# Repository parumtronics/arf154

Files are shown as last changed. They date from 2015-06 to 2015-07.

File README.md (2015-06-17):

# arf154 

Arf154 is an arduino compatible wireless network ready board.

The board core is the atsamr21g1x SoC. The device integrates a Cortex-M0 and a
IEEE 802.15.4 transceiver.

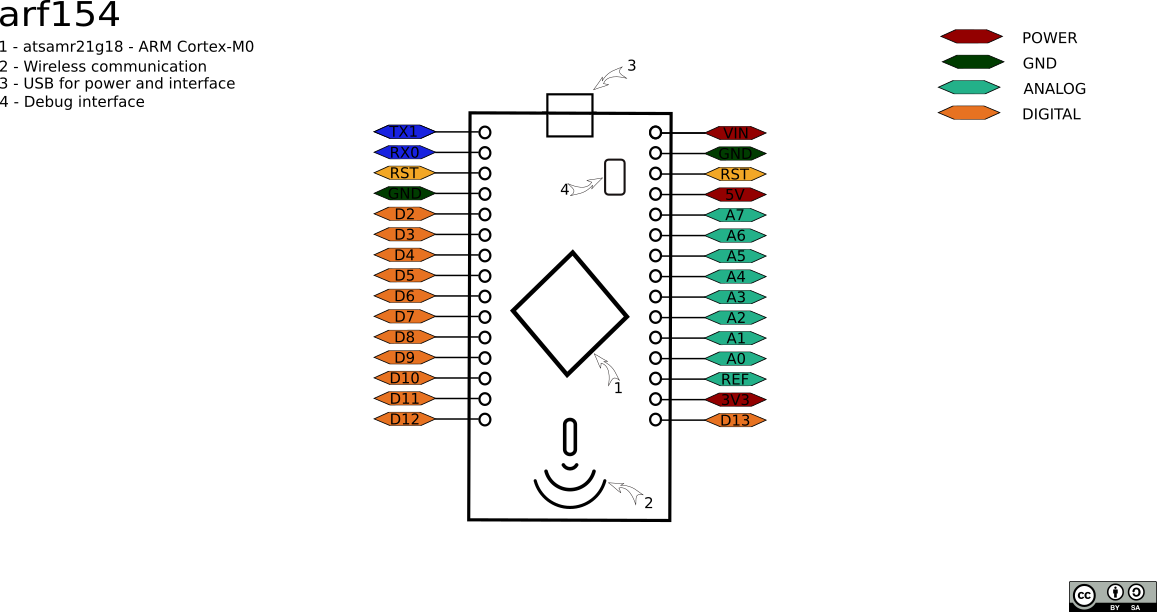
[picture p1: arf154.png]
Diagram


## Footprint

The design is targeting to be as compatible as possible with Arduino nano.

## How to program

The board can be programmed using the USB connector or trough the EMDBG using 
any Atmel software tools.

## Libraries

At this moment, there's no library but basic wireless communication libraries 
will be added in near future. Support for advanced features, as mesh network,
will be added later.

The board also is compatible with zigbee, 6lowpan and other network standart.

## Status

At this moment the schematics are almost done.

LICENSE: All work is released under the MIT license.

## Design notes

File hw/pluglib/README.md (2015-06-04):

# Pluglib

Kicad libraries for components used in the plugfects projects.

Parts are divided in the following categories

* Processing
* Analog
* Sensor

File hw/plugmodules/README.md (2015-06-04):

# plugmodules
Modular circuits library for kicad

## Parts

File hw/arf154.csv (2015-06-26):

Id | Designator | Package | Quantity | Designation | Supplier and ref
1 | C1 | C_0603_HandSoldering | 1 | 10uF
2 | C2,C3,C4,C5,C6,C7,C8,C10 | C_0603_HandSoldering | 8 | 100n
3 | C9,C11 | C_0603_HandSoldering | 2 | 10u
4 | P1,P2 | Pin_Header_Straight_1x15 | 2 | CONN_01X15
5 | P3 | Pin_Header_Straight_2x05 | 1 | CONN_02X05
6 | R1,R2 | R_0603_HandSoldering | 2 | 100K
7 | R3 | R_0603_HandSoldering | 1 | 10K
8 | U2 | SOT-223 | 1 | LD1117S33TR

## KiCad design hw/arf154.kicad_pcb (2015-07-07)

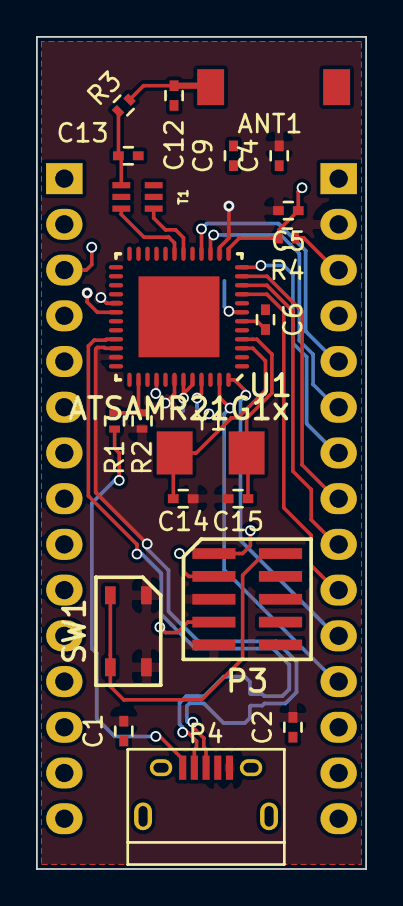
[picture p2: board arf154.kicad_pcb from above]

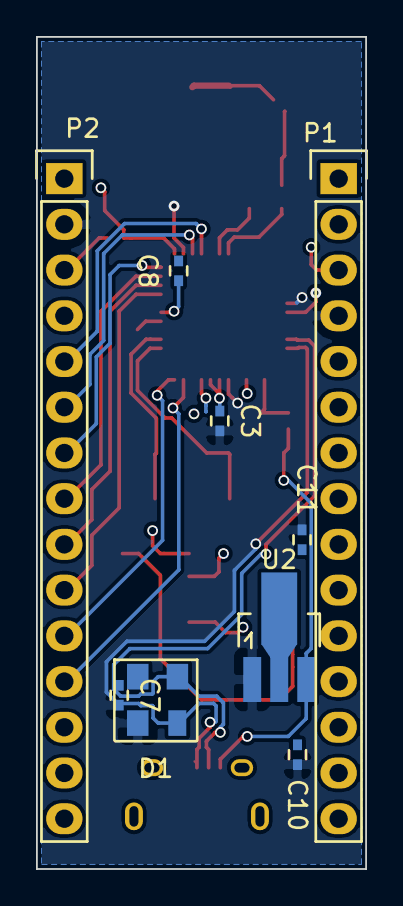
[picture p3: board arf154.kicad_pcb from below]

Board: 4 copper layers, 18.3 x 46.2 mm, 30 parts (9 on the bottom side), 26 nets.

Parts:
ANT1: antenna; CHIPANTENNA2dBi
C1: 10uF; C_0402
C2, C3, C4, C5, C6, C7, C8, C10: 100n; C_0402
C9, C11: 10u; C_0402
C12, C13: xF; C_0402
C14, C15: 18pF; C_0402
D1: PRTR5V0U2X; SOT143B
P1: Cn1; Pin_Header_Straight_1x15
P2: Cn2; Pin_Header_Straight_1x15
P3: CONN_02X05; CMxDBG
P4: USB_B; USB_Micro-B
R1, R2: 100K; R_0402
R3: xR; R_0402
R4: 10K; R_0402
SW1: SW_PUSH; tactileswitch
T1: 2450BM15A0015; JBALUN
U1: ATSAMR21G1x; QFN48EP
U2: AZ1117C; SOT89-3_Housing_Handsoldering
Y1: 16MHz; 2SMD

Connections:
/MainProcessor/BD+: T1.4, U1.18
/MainProcessor/BD-: T1.3, U1.19
/MainProcessor/PA4: P2.10, U1.9
/MainProcessor/PA5: P2.9, U1.10
/MainProcessor/PA6: P2.8, U1.11
/MainProcessor/PA7: P2.7, U1.12
/MainProcessor/PA8: P2.6, U1.15
/MainProcessor/PA9: P2.5, U1.16
/MainProcessor/PA23: R1.2, R2.1, U1.32
/MainProcessor/PB2: P2.12, U1.47
/MainProcessor/PB3: P2.11, U1.48
/MainProcessor/RST: C7.1, P1.3, P2.3, P3.10, R4.1, SW1.2, U1.40
/MainProcessor/SWCLK: P3.4, U1.45
/MainProcessor/SWDIO: P3.2, U1.46
/Sheet557215E3/D+: D1.3, P4.2, U1.33
/Sheet557215E3/D-: D1.2, P4.3, U1.34
GND: C1.2, C2.2, C3.2, C4.2, C5.2, C7.2, C10.2, C11.2, C14.2, C15.2, D1.1, P1.4, P2.2, P3.3, P3.5, P3.9, P4.4, P4.5, R2.2, SW1.1, U1.14, U1.29, U1.35, U1.42, U2.1
GNDA: C6.2, C8.2, C9.2, U1.5, U1.8, U1.17, U1.20
GNDREF: C12.2, C13.2, T1.2, T1.5, T1.6
unnamed: ANT1.1, C12.1, R3.2
unnamed: C13.1, R3.1, T1.1
unnamed: C14.1, U1.3, Y1.1
unnamed: C15.1, U1.4, Y1.2
VAA: C6.1, C8.1, C9.1, U1.6, U1.7
VCC: C10.1, D1.4, P4.1, R1.1, U2.3
VDD: C1.1, C2.1, C3.1, C4.1, C5.1, C11.1, P2.14, P3.1, R4.2, U1.13, U1.30, U1.36, U1.43, U1.44, U2.2

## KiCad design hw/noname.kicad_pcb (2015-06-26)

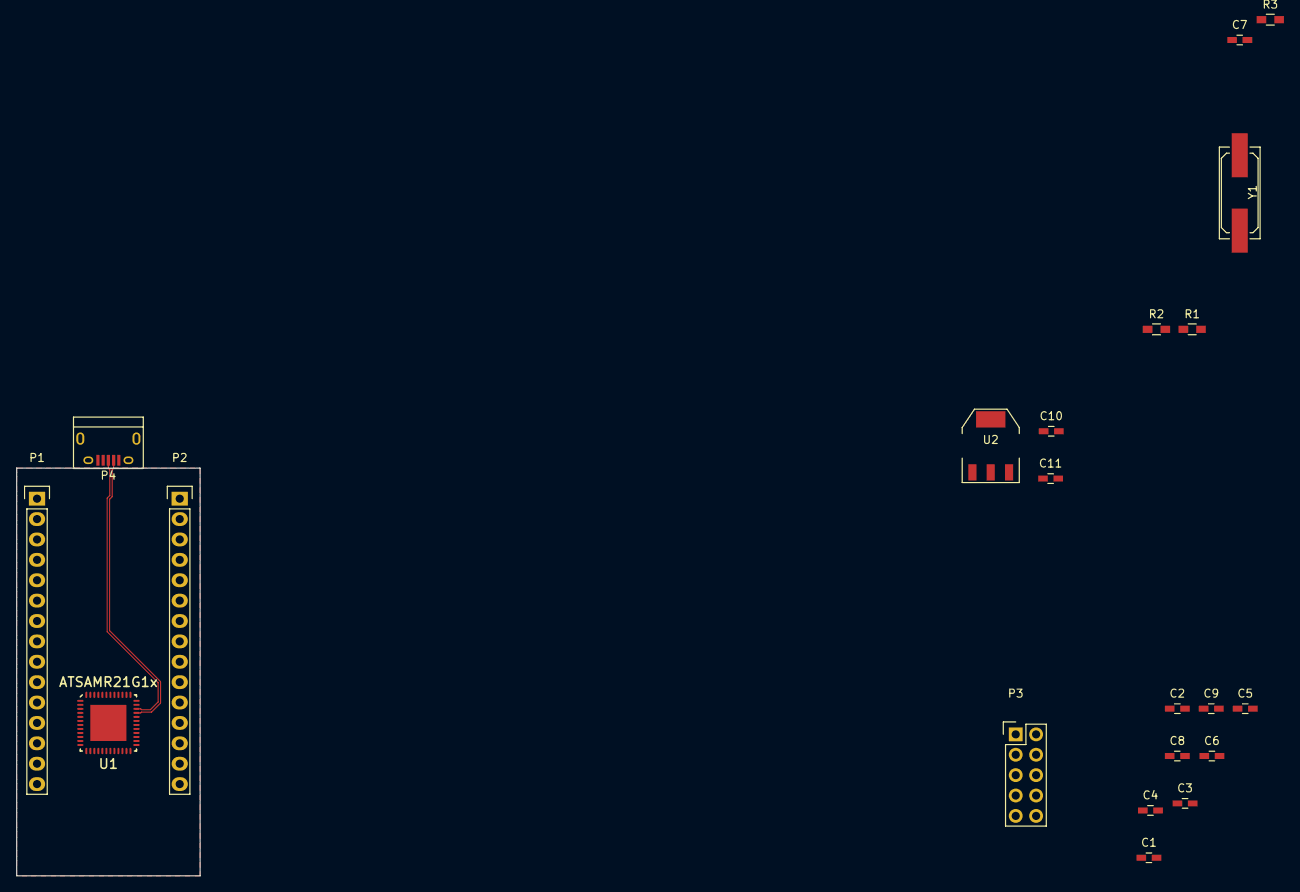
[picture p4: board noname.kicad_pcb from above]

Board: 4 copper layers, 22.9 x 50.8 mm, 21 parts (0 on the bottom side), 14 nets.

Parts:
C1: 10uF; C_0603_HandSoldering
C2, C3, C4, C5, C6, C7, C8, C10: 100n; C_0603_HandSoldering
C9, C11: 10u; C_0603_HandSoldering
P1, P2: CONN_01X15; Pin_Header_Straight_1x15
P3: CONN_02X05; Pin_Header_Straight_2x05
P4: USB_B; USB_Micro-B
R1, R2: 100K; R_0603_HandSoldering
R3: 10K; R_0603_HandSoldering
U1: ATSAMR21G1x; QFN48EP
U2: LD1117S33TR; SOT-223
Y1: 16MHz; Q_49U3HMS

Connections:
/MainProcessor/PA22: U1.31, U1.37
/MainProcessor/PA23: R1.2, R2.1, U1.32, U1.38
/MainProcessor/RST: C7.1, P3.10, R3.2, U1.40
/MainProcessor/SWCLK: P3.4, U1.45
/MainProcessor/SWDIO: P3.2, U1.46
/Sheet557215E3/D+: P4.2, U1.33
/Sheet557215E3/D-: P4.3, U1.34
GND: C1.2, C2.2, C3.2, C4.2, C5.2, C7.2, C10.2, C11.2, P3.3, P3.5, P3.9, P4.4, P4.5, R2.2, U1.14, U1.29, U1.35, U1.42, U2.1
GNDA: C6.2, C8.2, C9.2, U1.5, U1.8, U1.17, U1.20
unnamed: U1.3, Y1.1
unnamed: U1.4, Y1.2
VAA: C6.1, C8.1, C9.1, U1.6, U1.7
VCC: C10.1, P4.1, R1.1, U2.3
VDD: C1.1, C2.1, C3.1, C4.1, C5.1, C11.1, P3.1, R3.1, U1.13, U1.30, U1.36, U1.43, U1.44, U2.2

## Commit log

2015-06-04 Adding atsamr21q1x
    [atsamr21q1x.sch]
2015-06-04 Fix directory structure
    [atsamr21q1x.sch]
2015-06-04 Minor fix in MainProcessor circuit
    [atsamr21q1x.sch]
2015-06-04 Adding top design and .gitignore
    [arf154.sch]
2015-06-05 Added Balun and edbg connector
    [arf154.sch, atsamr21q1x.sch]
2015-06-05 Schematics for main processor done
    [arf154.sch, atsamr21q1x.sch]
2015-06-05 Added linear voltage regulator 3V3
    [arf154.sch, atsamr21q1x.sch, linear3v3.sch]
2015-06-05 Fix naming of atsamr21G SOC
    [arf154.sch, atsamr21q1x.sch, linear3v3.sch]
2015-06-06 Added USB circuit
    [arf154.sch, atsamr21q1x.sch, linear3v3.sch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]
2015-06-14 USB connections made, need to add protection in VBUS power flag connection to avoid problems when not powered from USB
    [arf154.sch]
2015-06-16 First schematics done. Need to finish connections and add power separation of VBUS-VCC
    [arf154.sch]
2015-06-16 Adding the cmp file with assigned parts footprint
2015-06-17 README update, Schematics almost done(need to finish power section)
    [arf154.sch, atsamr21q1x.sch, linear3v3.sch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]
2015-06-26 Started layout, minor gitignore modification
    [arf154.csv, arf154.kicad_pcb, arf154.sch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]
2015-06-28 Schematics change for a smaller regulator, added a new sch module, layout update
    [arf154.kicad_pcb, arf154.sch, atsamr21q1x.sch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]
2015-06-28 Modified power regulator
    [arf154.kicad_pcb, arf154.sch, atsamr21q1x.sch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]
2015-06-28 Layout update, footprint changed to 0402, atsam component fix
    [arf154.kicad_pcb, arf154.sch, atsamr21q1x.sch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]
2015-07-02 Layout for the analog pads and DRC fix on the USB signals
    [arf154.kicad_pcb, arf154.sch]
2015-07-04 Layout updated, need improvement on ground layers and a power switch
    [arf154.kicad_pcb, arf154.sch, atsamr21q1x.sch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]
2015-07-07 Layout modifications
    [arf154.kicad_pcb, arf154.sch, atsamr21q1x.sch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]
